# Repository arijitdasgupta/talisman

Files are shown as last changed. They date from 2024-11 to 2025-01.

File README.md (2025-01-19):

# Talisman

In at attempt to teach myself how to design PCBs, I made this trinket thingie to share with my friends. The board runs RP2040, and I am going to make some games for it.

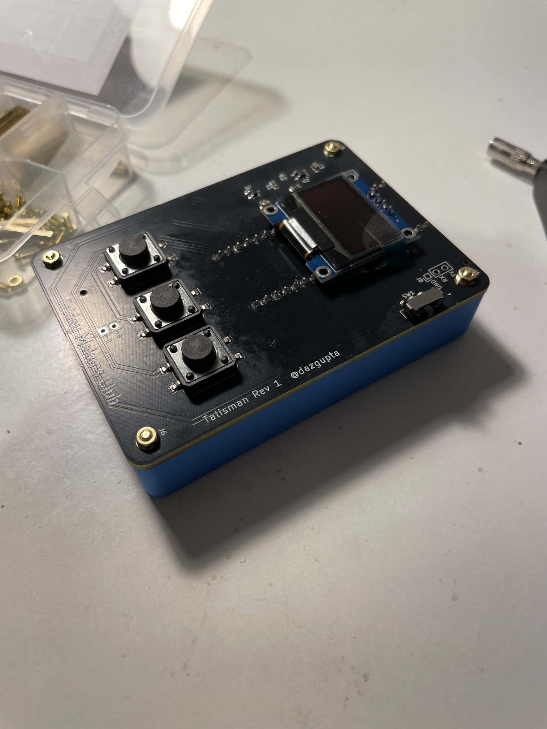
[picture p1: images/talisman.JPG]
Talisman


## Games that run on this

 - [Bike w Friends](https://github.com/arijitdasgupta/bike_w_friends/)
 - [Flappy Mycologist](https://github.com/arijitdasgupta/flappy_mycologist)

## Features

 - I2C SSD1306 based display
 - Raspberry Pi Pico brain
 - 3 x buttons
 - Shared power between battery & USB
 - Battery charging
 - 3D printable case

## Notes

The manufacturing process with PCB makers such as JLCPCB is a little convoluted, even though I added BOM, drills and rotation files those may not be usable for you. But the general schematic designs and part ids should be helpful if you decide to make one yourself. If you have any questions, do drop a note. I have purposefully omitted writing a build guide for this very reason, but I am happy to write on up if anyone needs it.

## TODO
 - Write assembly instructions

## What's Friday Makers Club?

TODO

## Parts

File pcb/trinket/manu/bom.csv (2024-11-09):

Comment | Designator | Footprint | LCSC Part Number
OLED2 | J1
OLED1 | J2
MountingHole1 | J3
MountingHole2 | J4
MountingHole3 | J5
MountingHole4 | J6
BATT | J7
DEBUG_UART | J8
BATT_ALT | J9
Pico | U1
LED | D1 | 0603 | C2286
1u | C2 | 0805 | C1712
4u7 | C3 | 0805 | C1746
10K | R1 | 0805 | C149881
470 | R2 | 0805 | C21266
Left | SW2 | C318915 | C318915
Center | SW3 | C318915 | C318915
Right | SW4 | C318915 | C318915
SW_SPDT | SW1 | SMD | C92658
DMP1045U | Q1 | SOT-23 | C177033
MCP73831T-2ACI_OT | U2 | SOT-23-5 | C424093

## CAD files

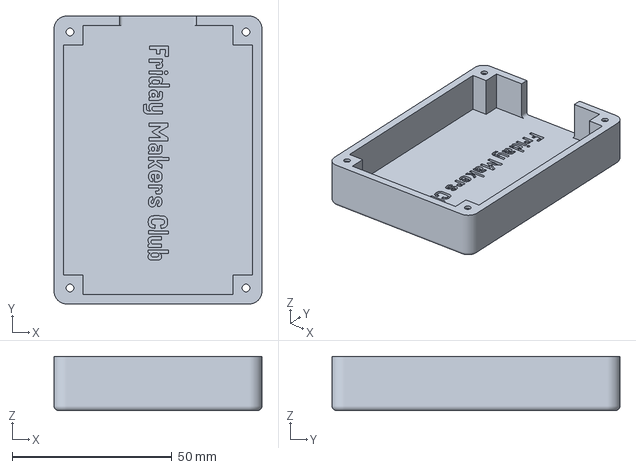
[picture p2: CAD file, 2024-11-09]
case/case-Body.3mf
65.0 x 90.0 x 17.0 mm

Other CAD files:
case/case.FCStd

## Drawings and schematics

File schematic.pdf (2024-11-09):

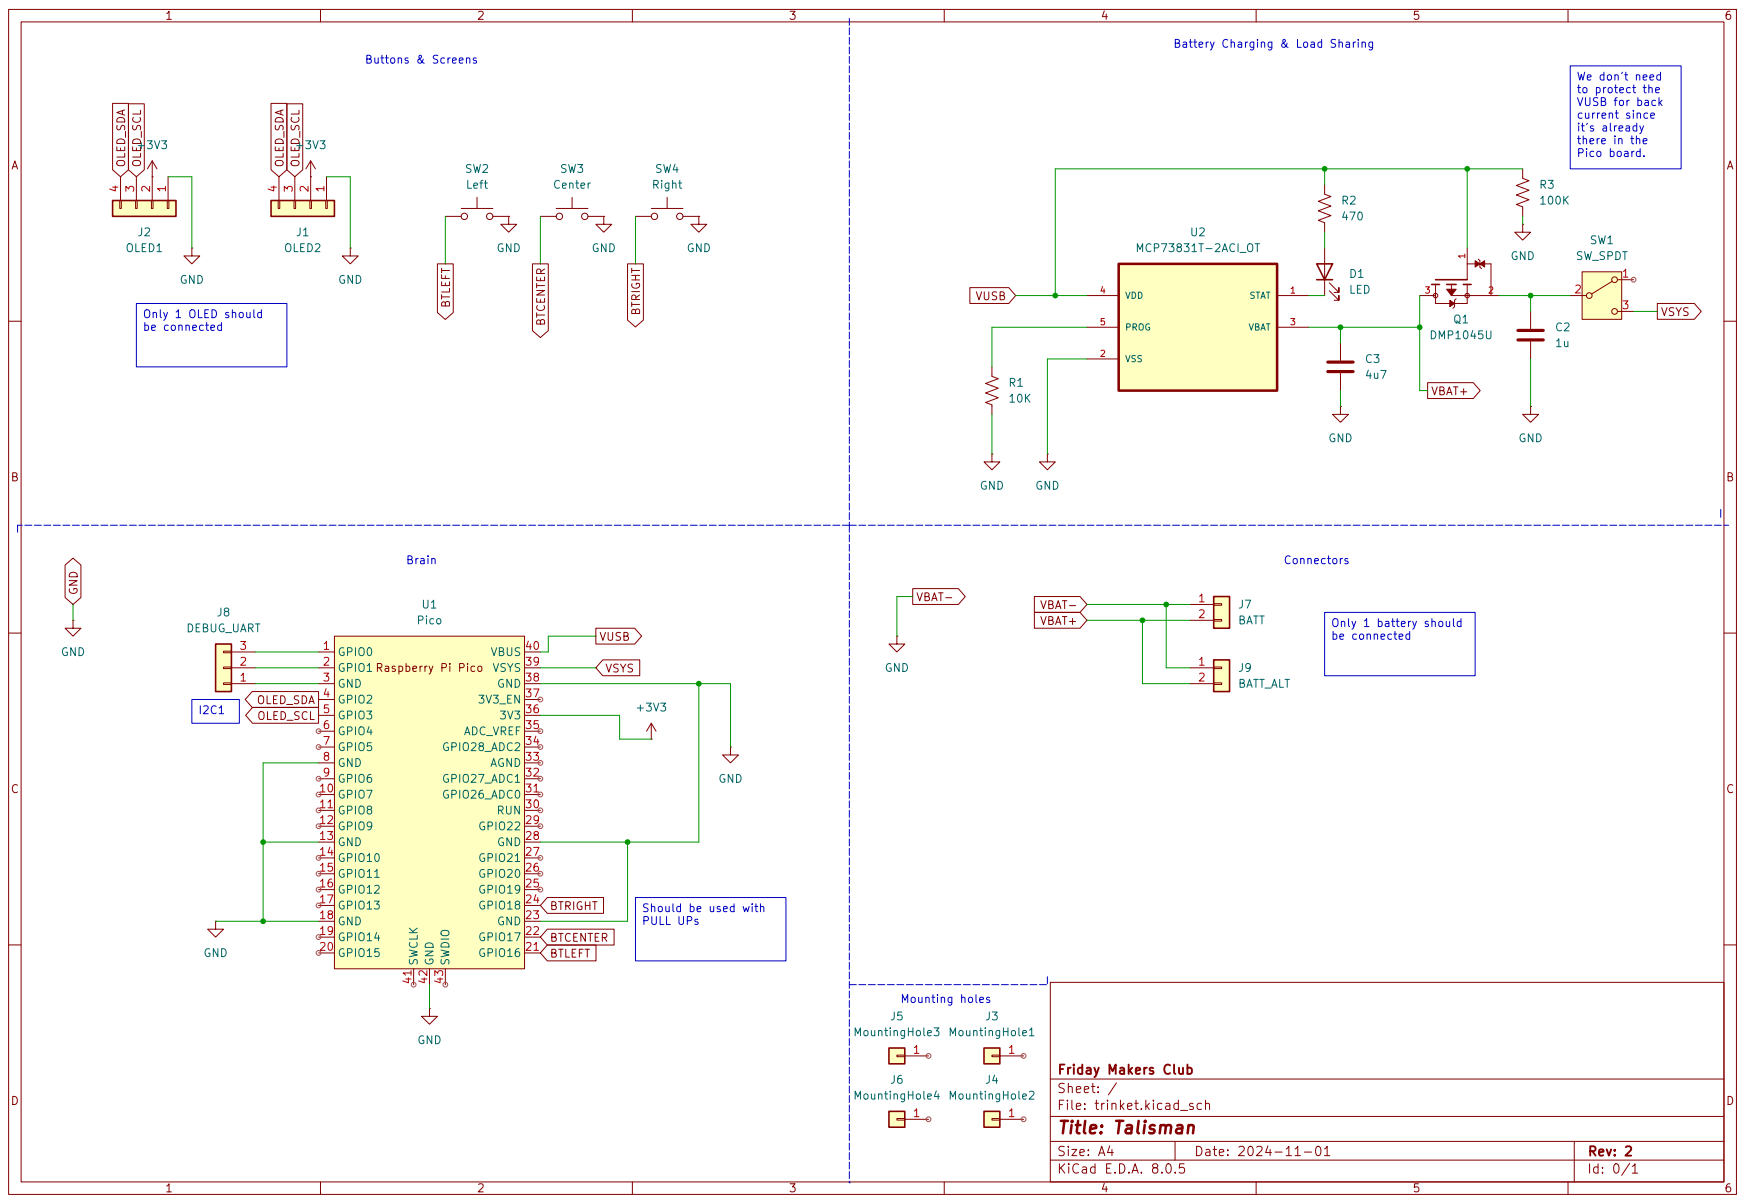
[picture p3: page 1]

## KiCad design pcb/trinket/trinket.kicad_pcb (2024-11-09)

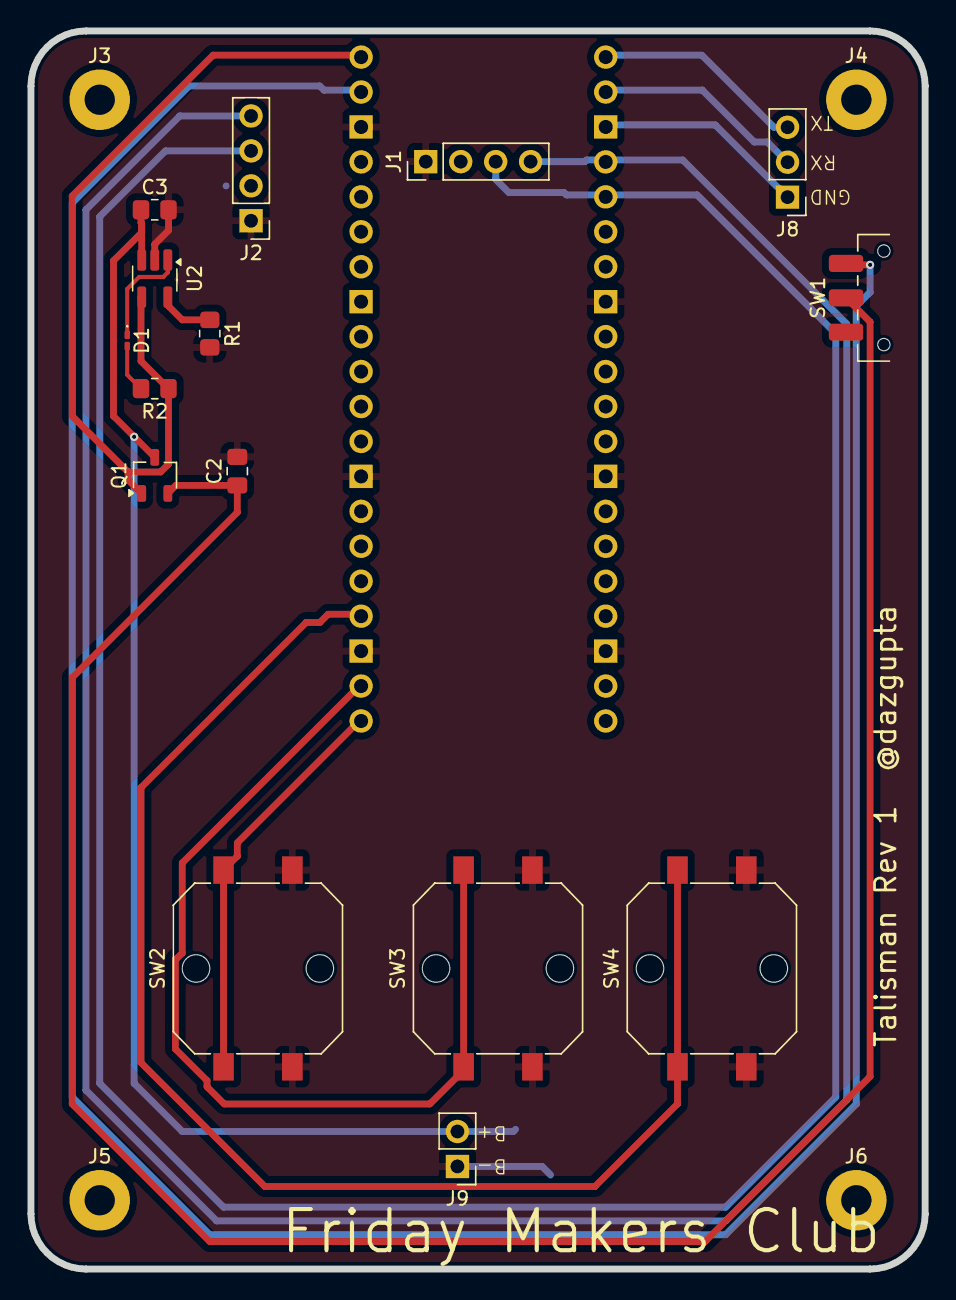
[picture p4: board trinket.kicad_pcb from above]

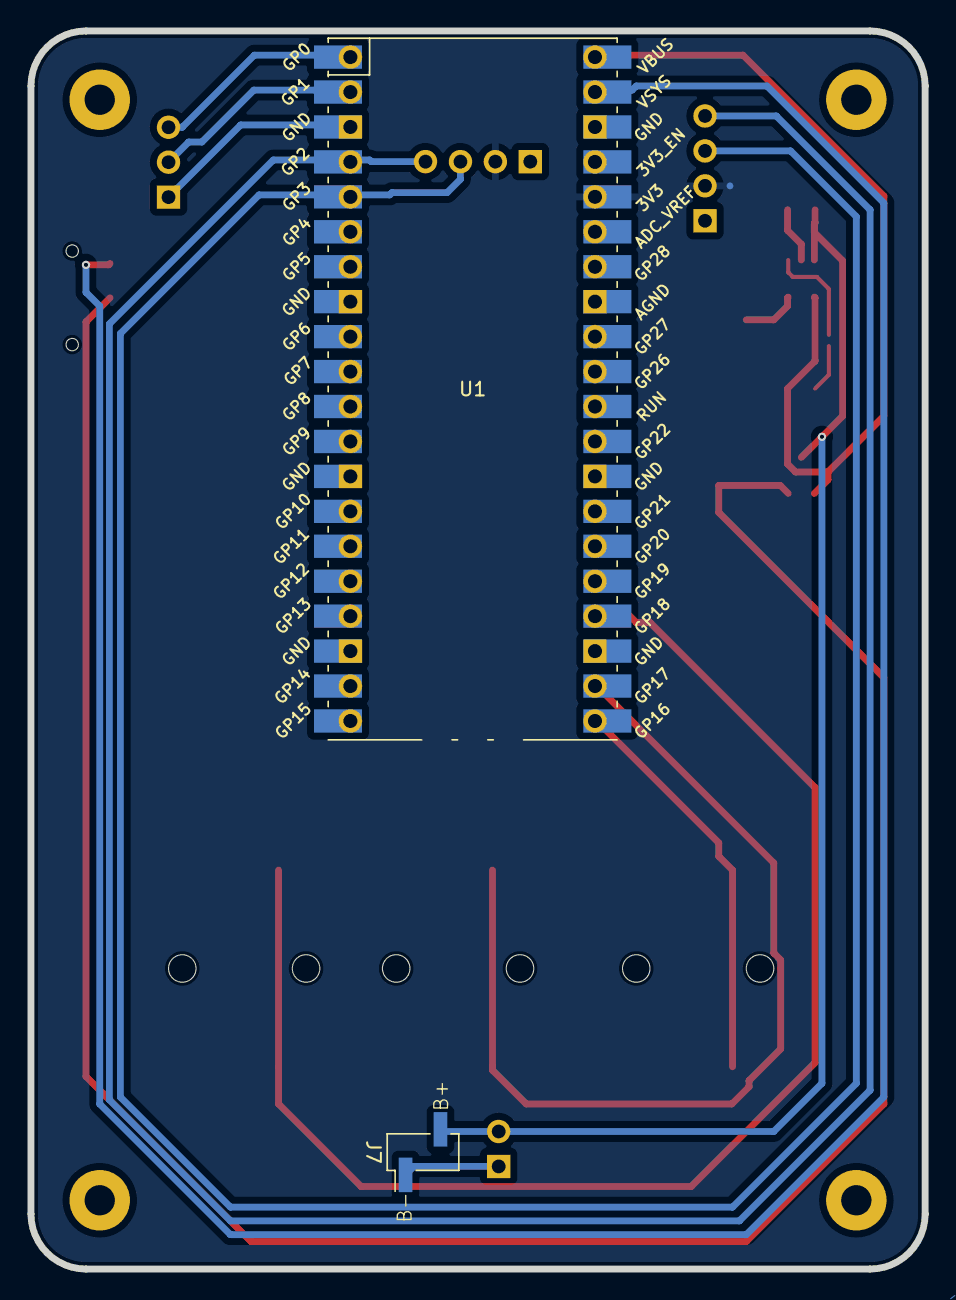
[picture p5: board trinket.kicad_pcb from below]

Board: 2 copper layers, 65.0 x 90.0 mm, 21 parts (2 on the bottom side), 17 nets.

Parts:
C2: 1u; C_0805_2012Metric_Pad1.18x1.45mm_HandSolder
C3: 4u7; R_0805_2012Metric_Pad1.20x1.40mm_HandSolder
D1: LED; LED_0201_0603Metric_Pad0.64x0.40mm_HandSolder
J1: OLED2; PinHeader_1x04_P2.54mm_Vertical
J2: OLED1; PinHeader_1x04_P2.54mm_Vertical
J3: MountingHole1; MountingHole_2.2mm_M2_Pad
J4: MountingHole2; MountingHole_2.2mm_M2_Pad
J5: MountingHole3; MountingHole_2.2mm_M2_Pad
J6: MountingHole4; MountingHole_2.2mm_M2_Pad
J7: BATT
J8: DEBUG_UART; PinHeader_DEBUG
J9: BATT_ALT; BATT_TH
Q1: DMP1045U; TSOT-23
R1: 10K; R_0805_2012Metric_Pad1.20x1.40mm_HandSolder
R2: 470; R_0805_2012Metric_Pad1.20x1.40mm_HandSolder
SW1: SW_SPDT; SW_SPDT_CK_JS102011SAQN
SW2: Left; SW_Push_1P1T_NO_CK_PTS125Sx43PSMTR
SW3: Center; SW_Push_1P1T_NO_CK_PTS125Sx43PSMTR
SW4: Right; SW_Push_1P1T_NO_CK_PTS125Sx43PSMTR
U1: Pico; RPi_Pico_SMD_TH
U2: MCP73831T-2ACI_OT; SOT-23-5_HandSoldering

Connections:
+3V3: J1.2, J2.2, U1.36 (3V3)
BTCENTER: SW3.1, U1.22 (GPIO17)
BTLEFT: SW2.1, U1.21 (GPIO16)
BTRIGHT: SW4.1, U1.24 (GPIO18)
GND: C2.2, C3.2, J1.1, J2.1, J7.1 (B-), J9.1 (B-), R1.2, SW2.2, SW3.2, SW4.2, U1.8 (GND), U1.13 (GND), U1.18 (GND), U1.23 (GND), U1.28 (GND), U1.38 (GND), U2.2 (VSS)
unnamed: D1.2 (A), R2.2
unnamed: D1.1 (K), U2.1 (STAT)
unnamed: J8.1 (GND), U1.3 (GND)
unnamed: J8.2 (RX), U1.2 (GPIO1)
unnamed: J8.3 (TX), U1.1 (GPIO0)
unnamed: C2.1, Q1.2, SW1.2 (B)
unnamed: R1.1, U2.5 (PROG)
OLED_SCL: J1.3, J2.3, U1.5 (GPIO3)
OLED_SDA: J1.4, J2.4, U1.4 (GPIO2)
VBAT+: C3.1, J7.2 (B+), J9.2 (B+), Q1.3, U2.3 (VBAT)
VSYS: SW1.3 (C), U1.39 (VSYS)
VUSB: Q1.1, R2.1, U1.40 (VBUS), U2.4 (VDD)

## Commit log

2024-11-09 fix case dimensions
    [case-Body.3mf, case.FCStd]
2024-11-26 update KiCAD stuff
